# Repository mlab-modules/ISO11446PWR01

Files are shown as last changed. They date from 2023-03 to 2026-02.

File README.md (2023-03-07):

#  ISO11446PWR01 - Trailer emulator

[ISO 11446 specifies a 13-pole electrical connector](https://en.wikipedia.org/wiki/ISO_standards_for_trailer_connectors#13-pin_trailer_connector_(ISO_11446)) between towing and towed vehicles with 12 volt electrical system. The module emulates connection of the trailer to get power supply and commands signals for connected devices. 

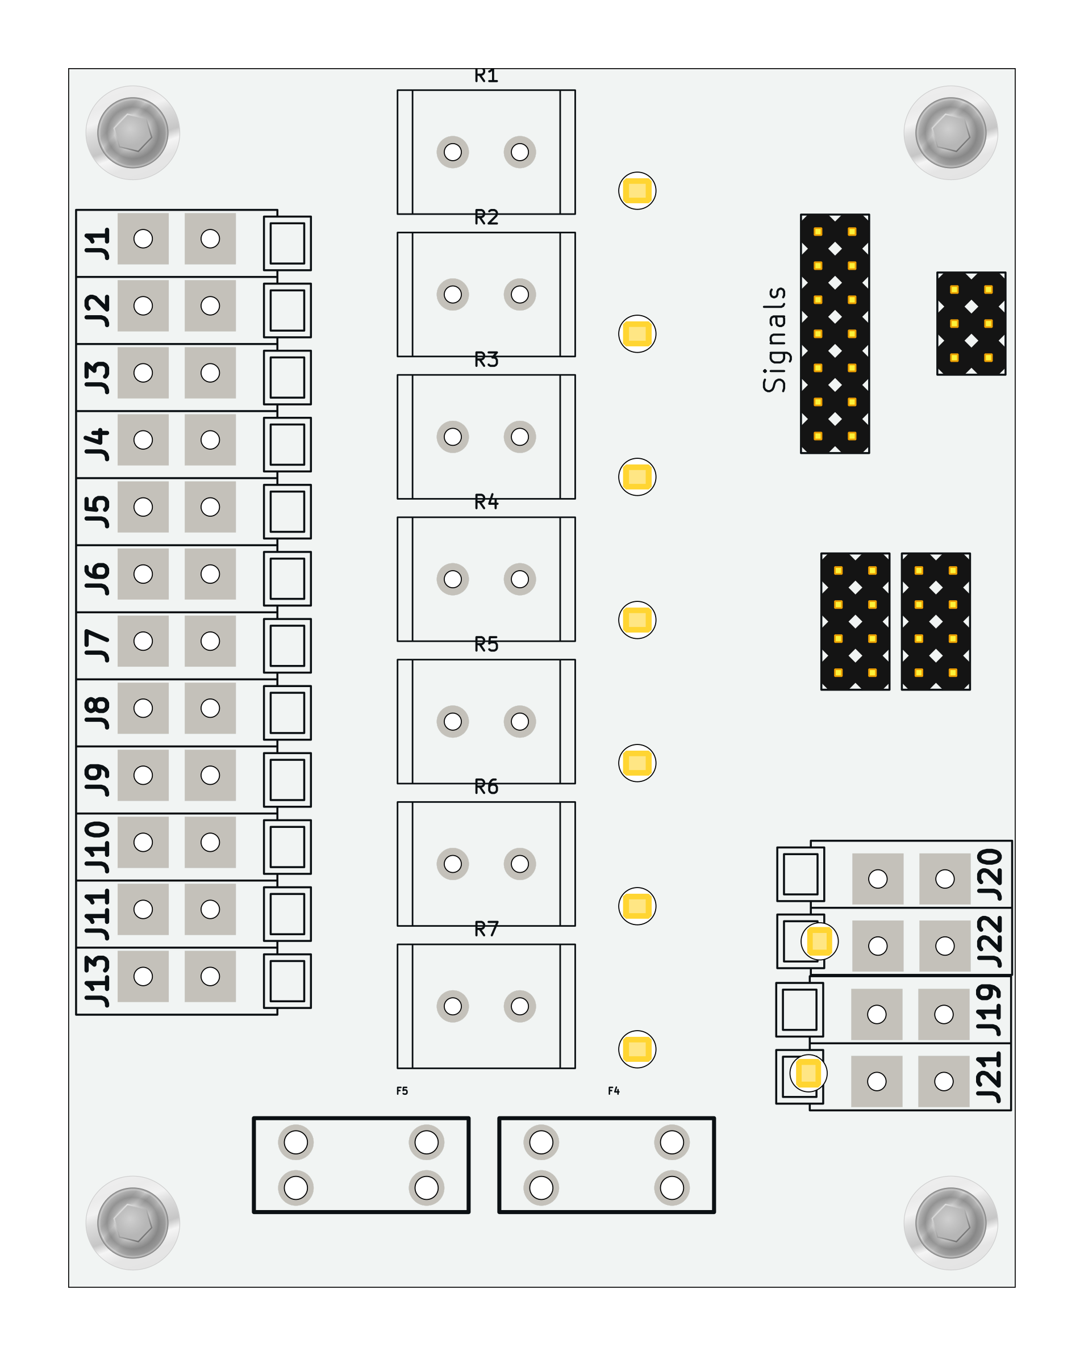
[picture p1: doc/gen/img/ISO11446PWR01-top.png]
ISO11446PWR01 PCB top


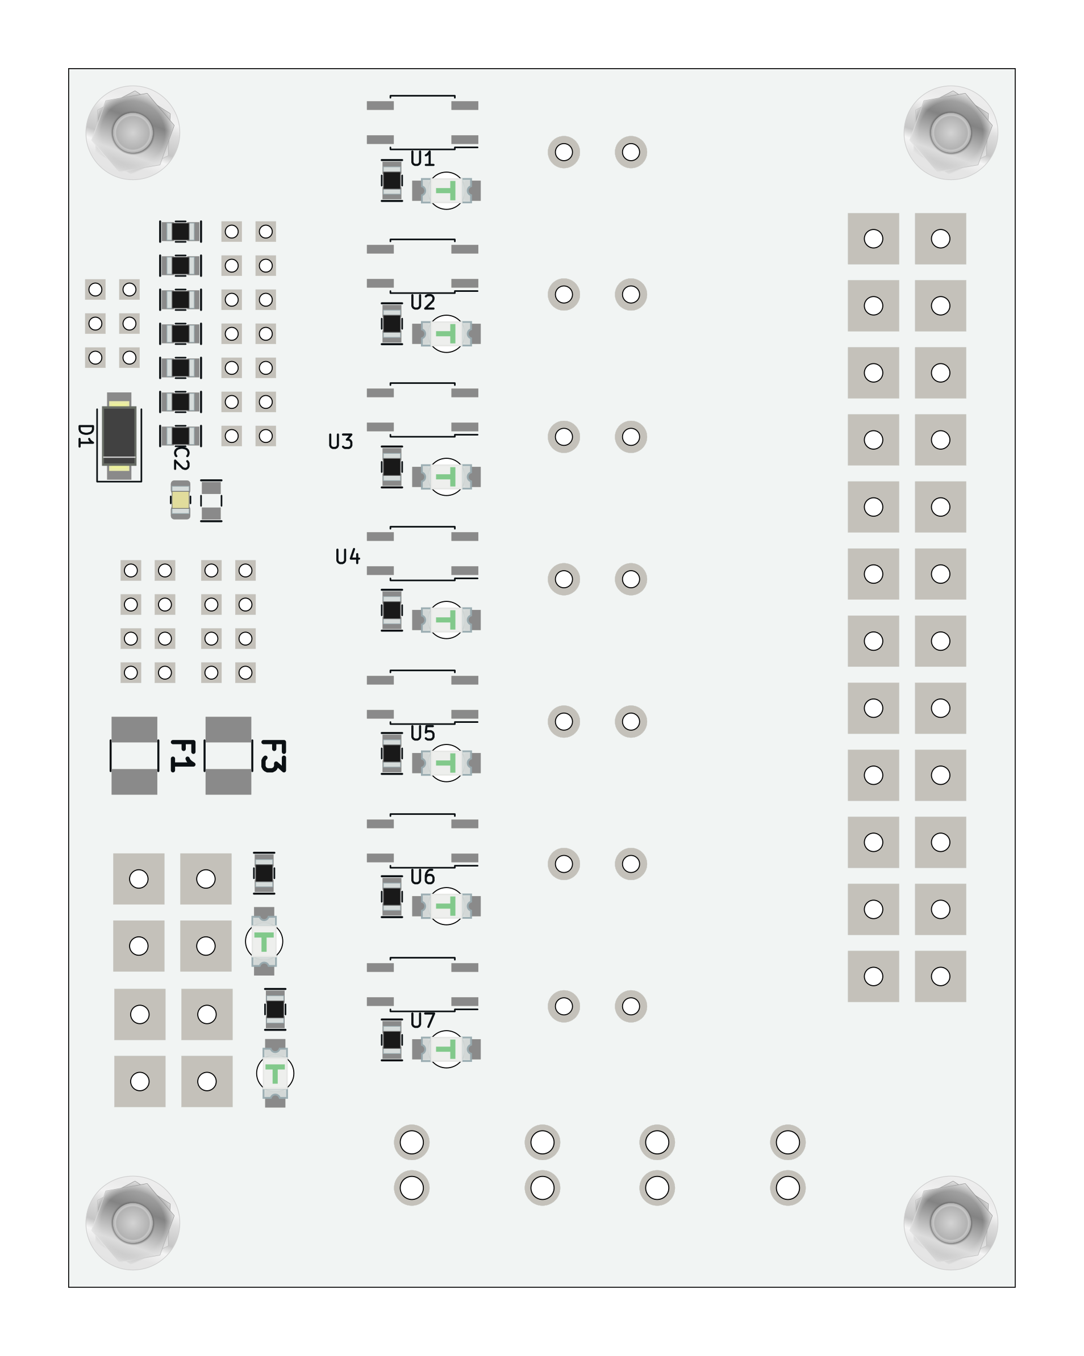
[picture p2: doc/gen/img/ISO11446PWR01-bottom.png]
ISO11446PWR01 PCB bottom


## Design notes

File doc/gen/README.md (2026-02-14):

# PCB

Board size: 70.61x90.93 mm (2.78x3.58 inches)

- This is the size of the rectangle that contains the board
- Thickness: 1.6 mm (63 mils)
- Material: FR4
- Finish: HAL
- Layers: 2
- Copper thickness: 35 µm

Solder mask: TOP / BOTTOM

- Color: Green

Silk screen: TOP / BOTTOM

- Color: White

# Important sizes

Clearance: 0.2 mm (8 mils)

Track width: N/A mm (N/A mils)

- By design rules: 0.2 mm (8 mils)

Drill: 1.0 mm (39 mils)

- Vias: N/A mm (N/A mils) [Design: 0.4 mm (16 mils)]
- Pads: 1.0 mm (39 mils)
- The above values are real drill sizes, they add 0.1 mm (4 mils) to plated holes (PTH)

Via: N/A/N/A mm (N/A/N/A mils)

- By design rules: 0.4/0.3 mm (16/12 mils)
- Micro via: yes [0.2/0.1 mm (8/4 mils)]
- Buried/blind via: yes
- Total: 0 (thru: 0 buried/blind: 0 micro: 0)

Outer Annular Ring: 0.26 mm (10 mils)

- By design rules: 0.26 mm (10 mils)

Eurocircuits class: 4A
- Using min drill 1.0 mm for an OAR of 0.26 mm

# General stats

Components count: (SMD/THT)

- Top: 0/33 (THT)
- Bottom: 37/0 (SMD)

Defined tracks:

Used tracks:

Defined vias:

Used vias:

Holes (excluding vias):

- 0.89 mm (35 mils) (36)
- 1.2 mm (47 mils) (14)
- 1.3 mm (51 mils) (32)
- 1.65 mm (65 mils) (8)
- 2.7 mm (106 mils) (9)
- 3.0 mm (118 mils) (4)

Oval holes:

Drill tools (including vias and computing adjusts and rounding):

- 1.0 mm (39 mils) (36)
- 1.3 mm (51 mils) (14)
- 1.4 mm (55 mils) (32)
- 1.75 mm (69 mils) (8)
- 2.7 mm (106 mils) (9)
- 3.1 mm (122 mils) (4)

Solder paste stats:

Using a paste with 87.75 % alloy, that has an specific gravity for the alloy of 7.4 g/cm³
and 1.0 g/cm³ for the flux. This paste has an specific gravity of  4.15 g/cm³.

The stencil thickness is  0.12 mm.

| Side | Pads with paste | Area [mm²] | Paste [g] |
|---|---|---|---|
| Total  | 88 | 147.85 | 0.74 |

Note: this is just an approximation to the theoretical value. Margins of the solder mask and waste aren't computed.

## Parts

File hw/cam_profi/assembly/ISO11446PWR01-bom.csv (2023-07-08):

Component | Description | Part | References | Value | Footprint | Quantity Per PCB | Datasheet | ust_id
1 |  | C_Small-Device-ISM02A-rescue | C2 | 100nF | C_0805_2012Metric | 1 |  | 5c70984812875079b91f8bf2
2 |  | C_Small-Device-ISM02A-rescue | C1 | 10uF | SMD-0805 | 1 |  | 5c70984812875079b91f8bbe
3 |  | D_ZENER-MLAB_D | D1 | BZV55C-5,6V | D_SMA | 1 |  | 5c70984512875079b91f88b2
4 | Light emitting diode | LED | D2D3D4D5D6D7D8D9D10 | LED | LED_1206 | 9 | ~
5 | Fuse | Fuse | F4F5 | 16A | Fuse-Keystone-3557-2 | 2 | https://www.tme.eu/cz/details/keys3557-2/automobilni-pojistkova-pouzdra/keystone/3557-2/
6 | Resettable fuse, polymeric positive temperature coefficient | Polyfuse | F1F3 | SD110-16 | 1812 | 2 | ~
7 | 2x04 2.54 mm pitch header, 2 pins next to each other are connected | HEADER_2x04_PARALLEL | J16J18 | 2x4 | Straight_2x04 | 2
8 | 2x03 2.54 mm pitch header, 2 pins next to each other are connected | HEADER_2x03_PARALLEL | J14 | 3.3-5V | Straight_2x03 | 1
9 | 2x07 2.54 mm pitch header, 2 pins next to each other are connected | HEADER_2x07_PARALLEL | J15 | Signals | Straight_2x07 | 1
10 | Generic connector, single row, 01x01, script generated (kicad-library-utils/schlib/autogen/connector/) | Conn_01x01_Female | J1J2J3J4J5J6J7J8J9J10J11J13J19J20J21J22 | WAGO 256-401 | WAGO256 | 16 | ~
11 | Resistor | R | R1R2R3R4R5R6R7 | 33R | R_Radial_Power_L13.0mm_W9.0mm_P5.00mm | 7 | ~
12 | Resistor | R | R10R11R14R15R19R20R21 | 510R | SMD-0805 | 7 | ~
13 | Resistor | R | R8R9R12R13R16R17R18R22R23 | 1k | SMD-0805 | 9 | ~
14 | DC Optocoupler, Vce 35V, CTR 50%, SO-4 | LTV-357T | U1U2U3U4U5U6U7 | LTV-357T | SO-4_4.4x3.6mm_P2.54mm | 7 | https://www.buerklin.com/medias/sys_master/download/download/h91/ha0/8892020588574.pdf | 5c70984412875079b91f8789

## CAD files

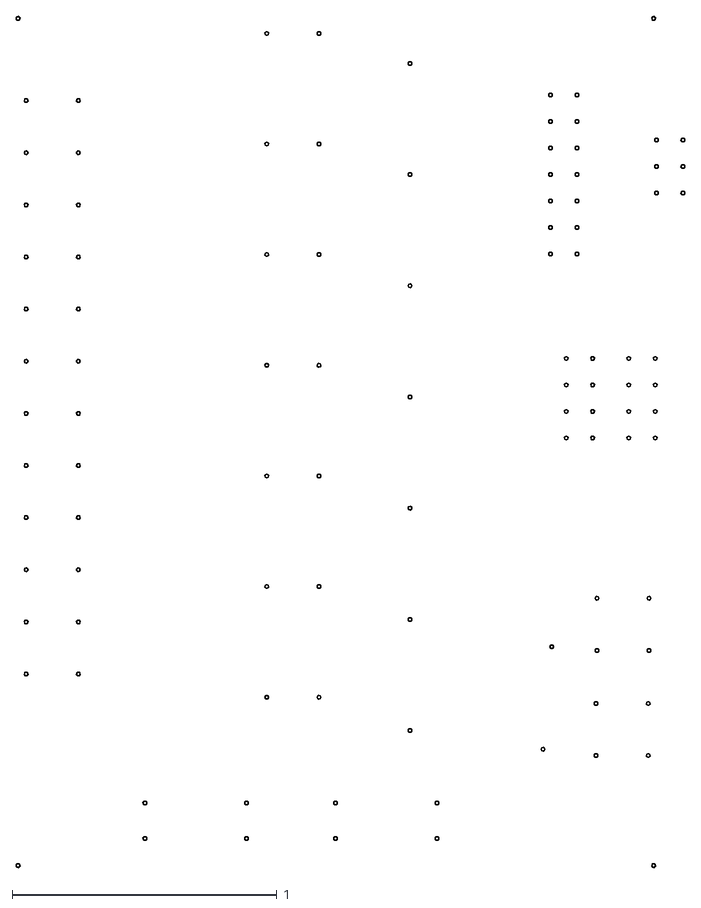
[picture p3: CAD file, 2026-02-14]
doc/gen/dxf/ISO11446PWR01-User_Eco2.dxf
2.52 x 3.21

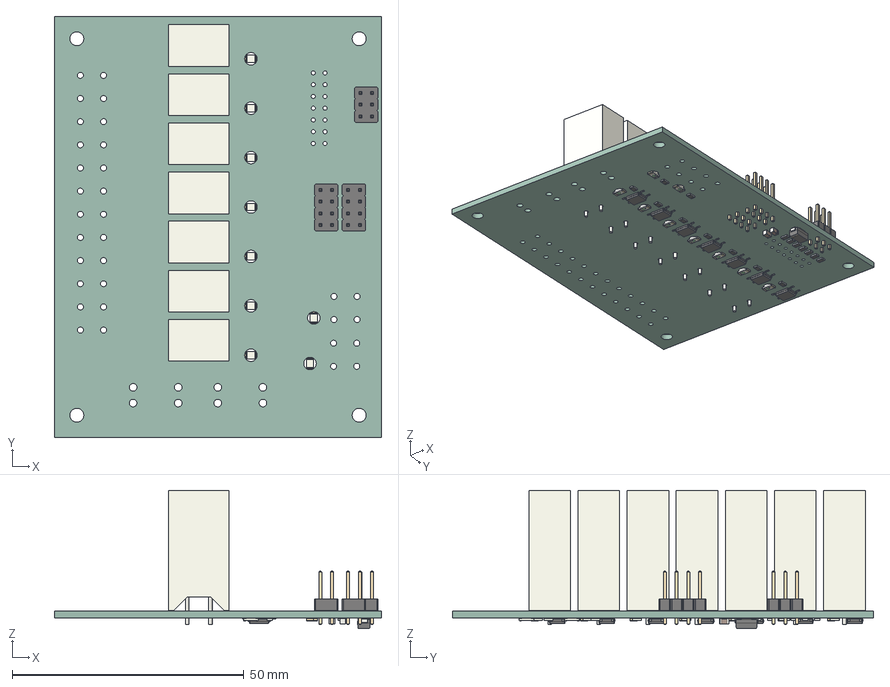
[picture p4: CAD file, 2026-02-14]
doc/gen/ISO11446PWR01.step
70.6 x 90.9 x 29.9 mm
R_Radial_Power_L13.0mm_W9.0mm_P5.00mm x 7
PinHeader_2x04_P2.54mm_Vertical x 2
PinHeader_2x03_P2.54mm_Vertical
LED_1206_3216Metric x 9
R_0805_2012Metric x 16
SO-4_4.4x3.6mm_P2.54mm x 7
C_0805_2012Metric x 2
D_SMA
kibot_23s9yeyt_PCB

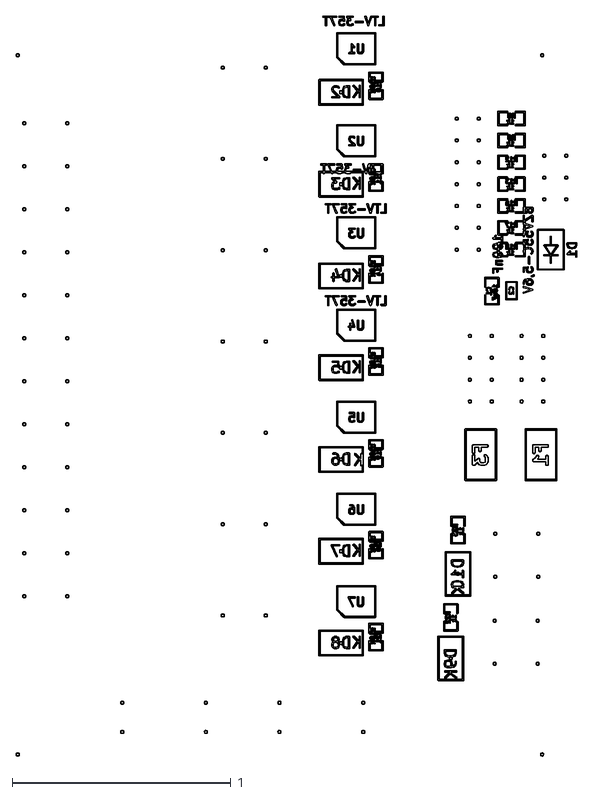
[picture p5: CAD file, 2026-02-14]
doc/gen/dxf/ISO11446PWR01-B_Fab.dxf
2.57 x 3.39

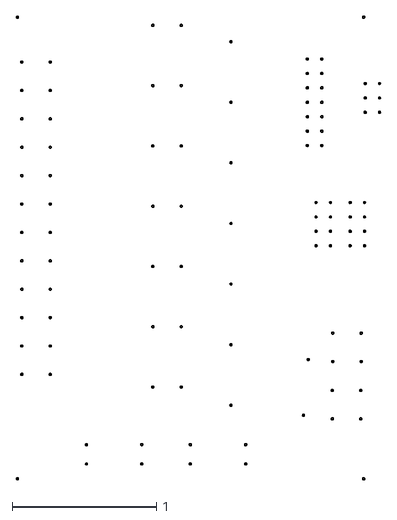
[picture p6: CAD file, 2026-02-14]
doc/gen/dxf/ISO11446PWR01-B_Adhesive.dxf
2.52 x 3.21

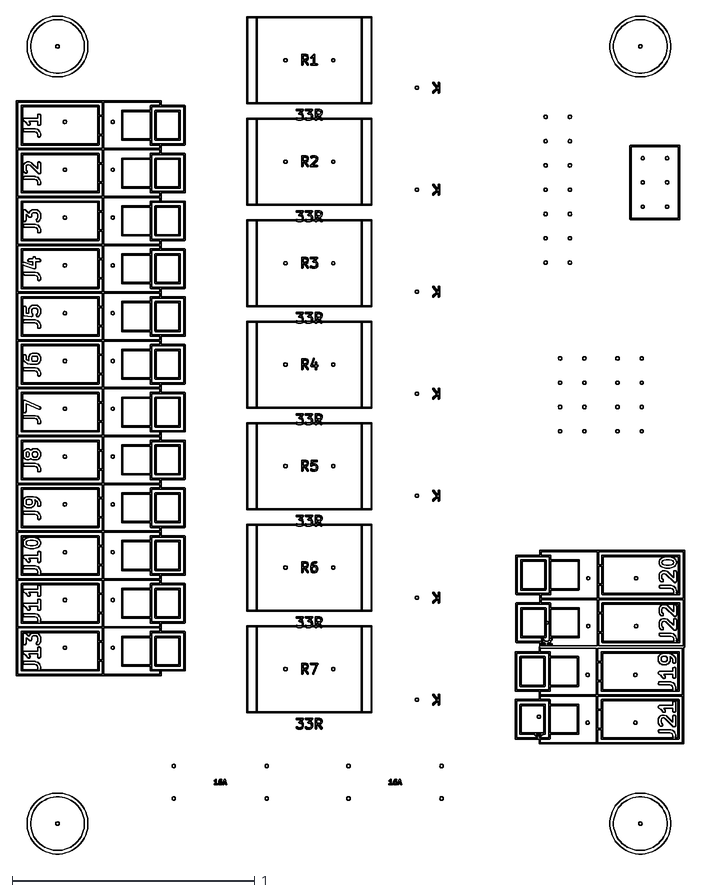
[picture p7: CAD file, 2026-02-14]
doc/gen/dxf/ISO11446PWR01-F_Fab.dxf
2.75 x 3.45

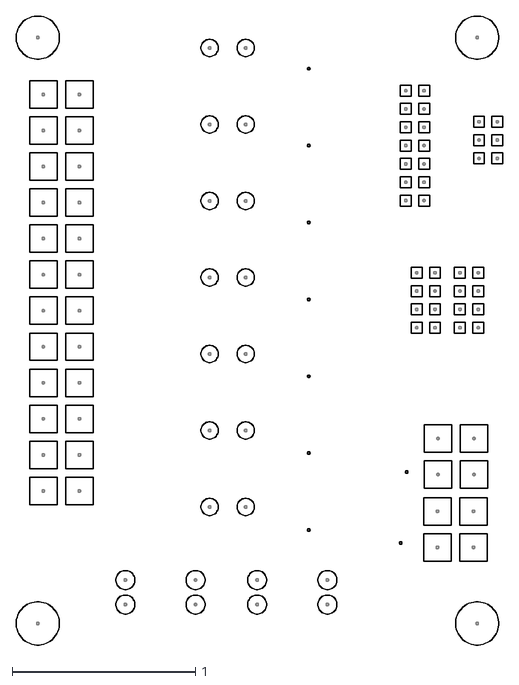
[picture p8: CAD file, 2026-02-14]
doc/gen/dxf/ISO11446PWR01-F_Cu.dxf
2.66 x 3.44

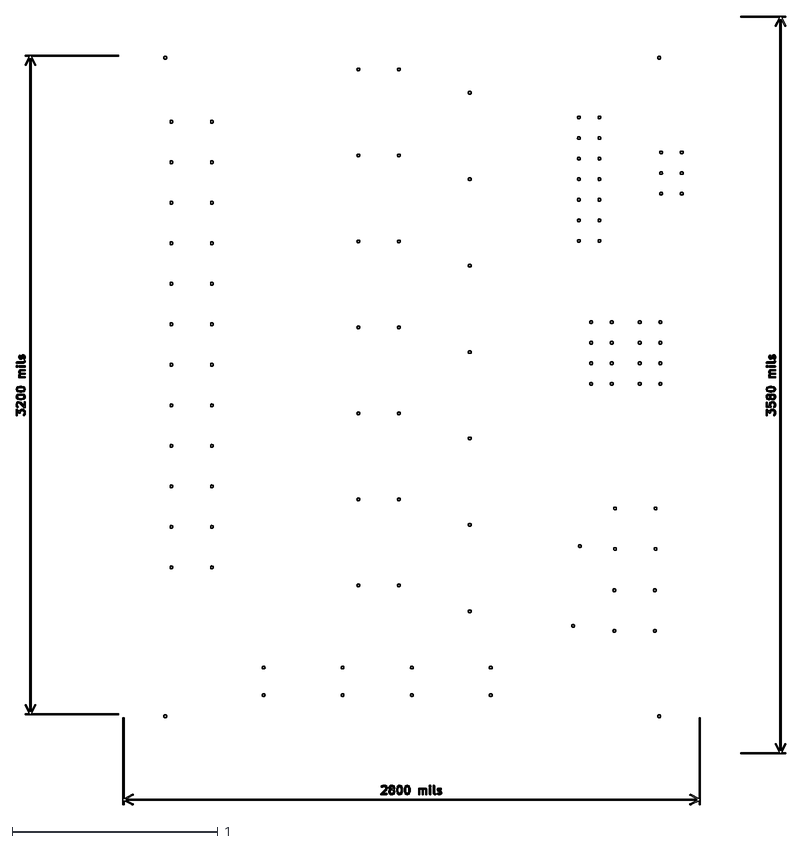
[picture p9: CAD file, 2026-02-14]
doc/gen/dxf/ISO11446PWR01-User_Comments.dxf
3.74 x 3.83

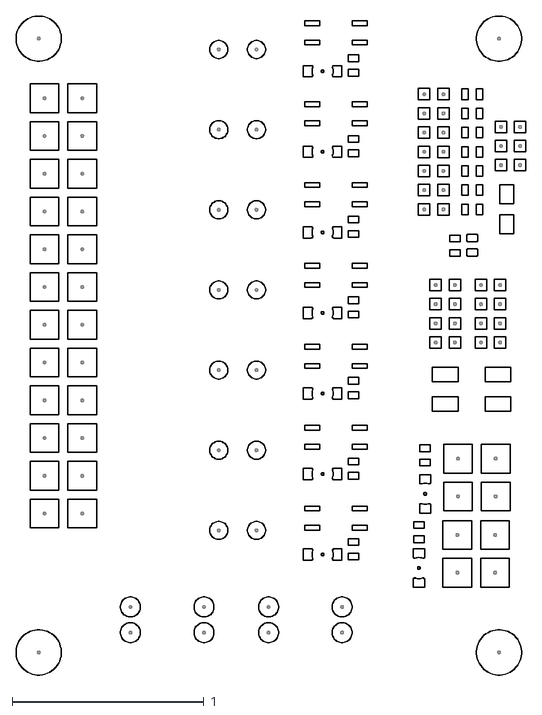
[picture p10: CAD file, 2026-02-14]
doc/gen/dxf/ISO11446PWR01-B_Cu.dxf
2.66 x 3.44

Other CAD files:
doc/gen/dxf/ISO11446PWR01-B_Courtyard.dxf
doc/gen/dxf/ISO11446PWR01-B_Mask.dxf
doc/gen/dxf/ISO11446PWR01-B_Paste.dxf
doc/gen/dxf/ISO11446PWR01-B_Silkscreen.dxf
doc/gen/dxf/ISO11446PWR01-Edge_Cuts.dxf
doc/gen/dxf/ISO11446PWR01-F_Courtyard.dxf
doc/gen/dxf/ISO11446PWR01-F_Mask.dxf
doc/gen/dxf/ISO11446PWR01-F_Silkscreen.dxf

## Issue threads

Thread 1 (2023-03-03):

Power supply availability test

kaklik, 2023-03-03:
Zkusil jsem udělat jednoduchý test pomocí zapojení, které jsem vytvořil z výkonových rezistorů podle  [wiki stránky s popisem ISO_11446](https://cs.wikipedia.org/wiki/ISO_11446). Pro vyzkoušení jsem použil náhodné výkonové rezistory mezi 33-56 Ohm.

Výsledkem je, že Karoq korektně detekoval přívěs

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

Zároveň začaly být měřitelná obě výstupní napájení. Tohle je spínané napájení, které je k dispozici jen při nastartovaném motoru (nestačí zapnuté zapalování).

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

Tohle je trvalé napájení, které je přítomné i když je auto zamčené.

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

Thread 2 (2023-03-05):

Connecting cable

kaklik, 2023-03-05:
Aby emulátor dával smysl, tak se musí připojit k zásuvce přívěsu z kufru auta. To ale znamená použít 12ti žilový kabel, který se skřípne do kufru, tak aby po něm netekla dovnitř voda.

Znamená to do kufru přivést poměrně [tlustý kabel](https://www.tme.eu/cz/details/heat180sihf-12g1.5/vicezilove-kabely-silikonove/lapp/0046039/), protože průřez napájecích vodičů v autozásuvce je 2.5mm², tak je nemá smysl připojovat menším průřezem než 1.5mm².

Existují i [ploché kabely](https://www.tme.eu/cz/details/neo-flach-12g1.5/vicezilove-kabely-nestinene/helukabel/28006/), ale jsou dost drahé.

roman-dvorak, 2023-03-05:
Jsou dvě možná řešení:

1) Vícežilový kabel s menším průřezem, kde výkonové vodiče budou znásobeny.

2) Rozdělit to na více kabelů. Pro to by bylo podstatné zjistit, jestli koule může být v zavřeném stavu. Pak by tím bylo vyřešeno krytí proti vodě.

kaklik, 2023-03-05:
> Jsou dvě možná řešení:
>
>     1. Vícežilový kabel s menším průřezem, kde výkonové vodiče budou znásobeny.

Tohle řešení nevychází tak, že by to snižovalo celkový průměr kabelu.

>
>     2. Rozdělit to na více kabelů. Pro to by bylo podstatné zjistit, jestli koule může být v zavřeném stavu. Pak by tím bylo vyřešeno krytí proti vodě.

To krytí proti vodě se tím nevyřeší. Na ten konektor ze spodu normálně bude cákat voda. Předpokládám, že může být v zavřeném stavu, ale nevidim moc co by se tím získalo. Vzhledem k tomu, že při aktivaci vozíku přestanou fungovat ultrazvukové parkovací senzory, tak to není zrovna moc pro trvalý zapojení.

>
> (plochý kabel bude mít s vodotěsností v konetoru stejný problém jako větší počet tenčích kabelů)

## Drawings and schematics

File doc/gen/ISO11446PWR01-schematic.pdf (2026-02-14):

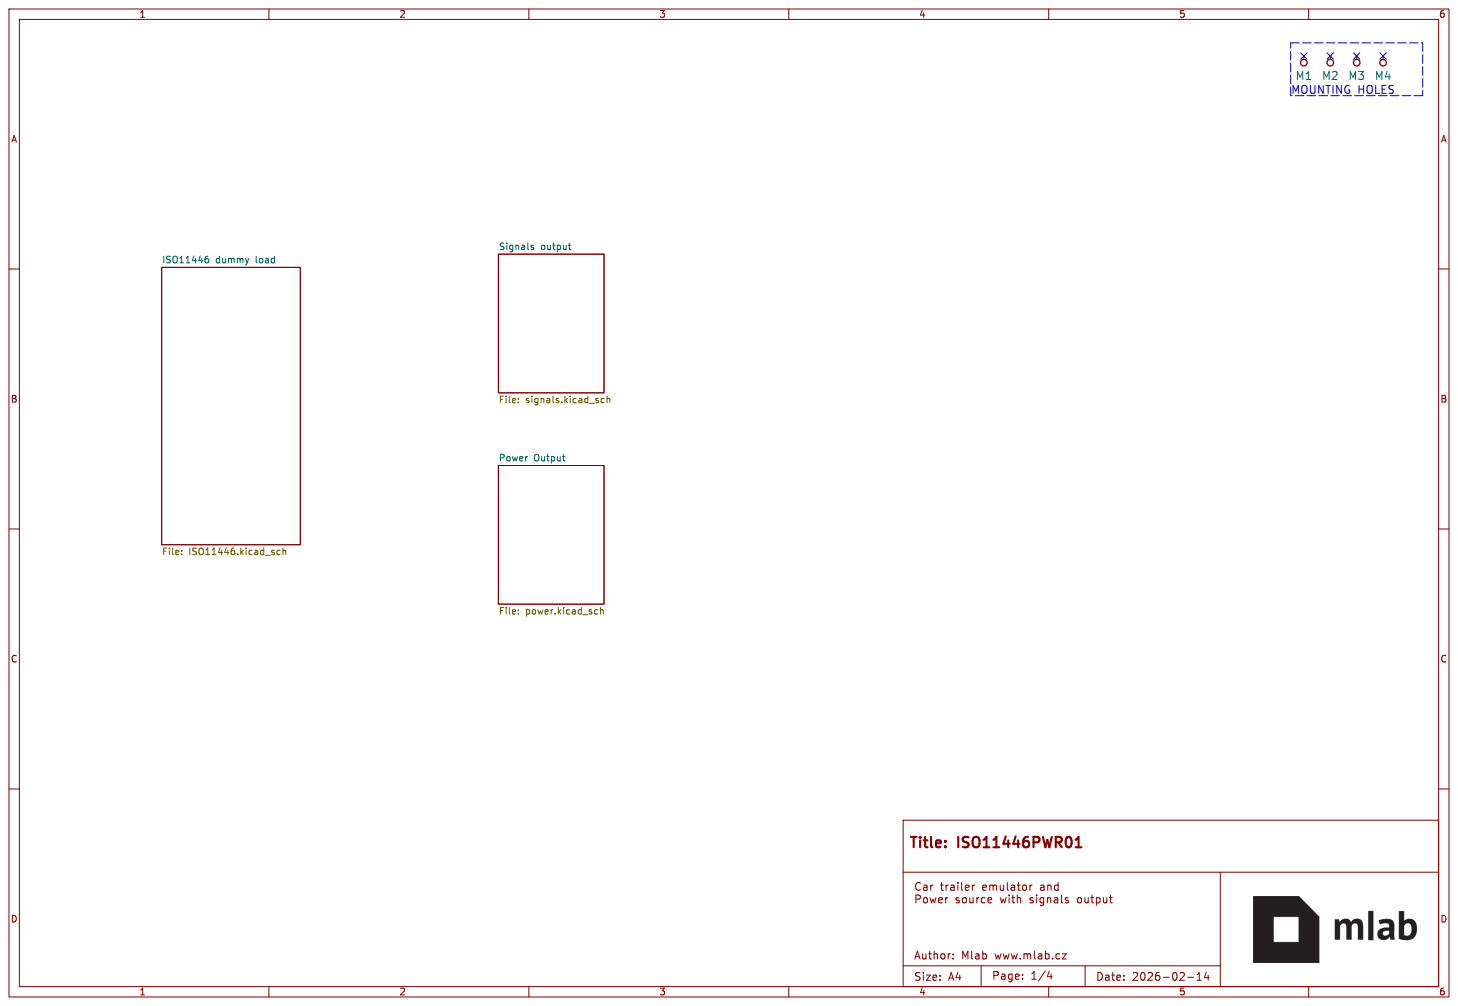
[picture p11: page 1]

Signals output File: signals.kicad_sch

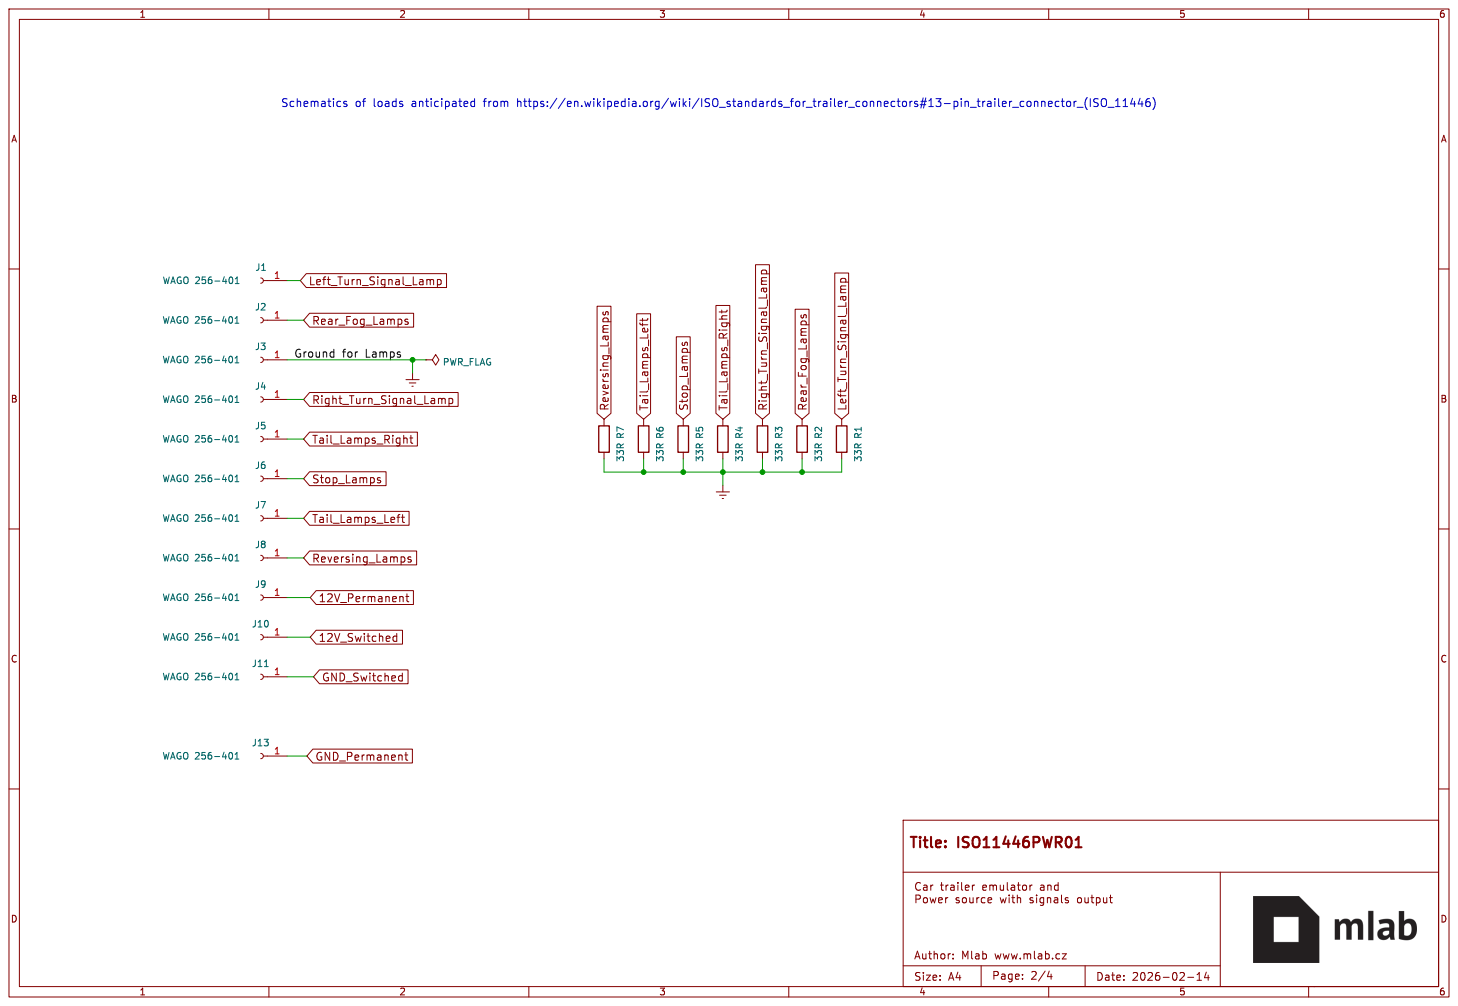
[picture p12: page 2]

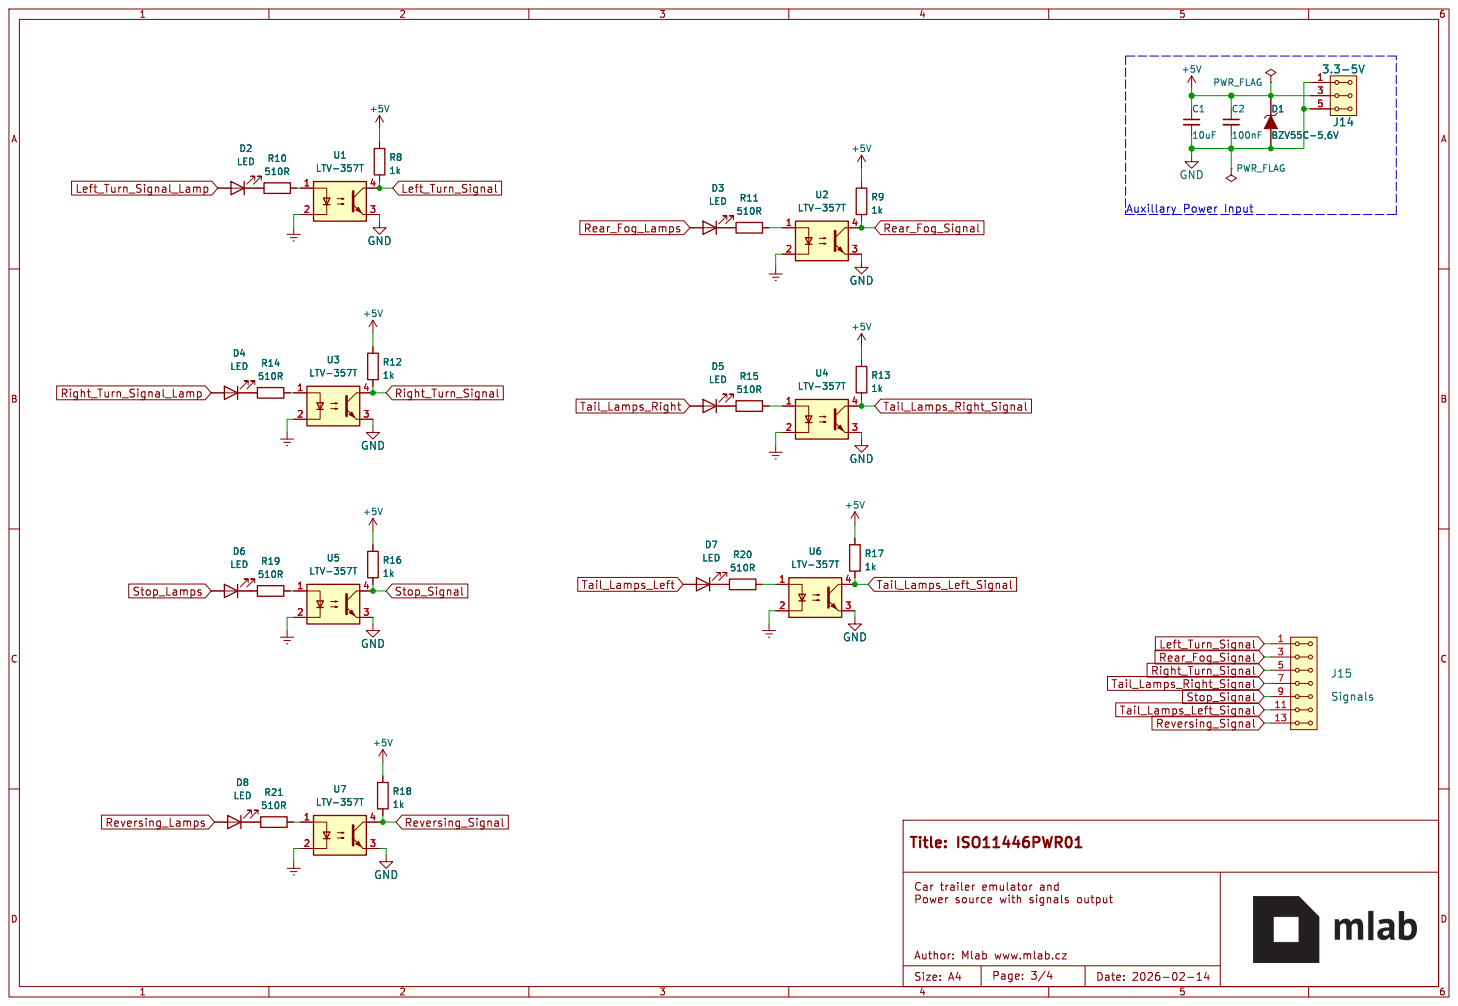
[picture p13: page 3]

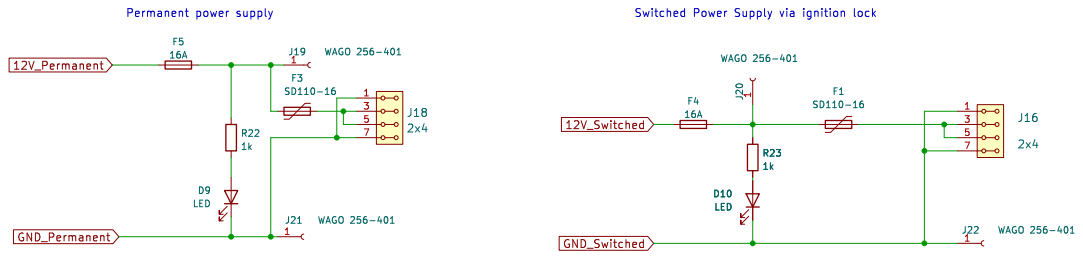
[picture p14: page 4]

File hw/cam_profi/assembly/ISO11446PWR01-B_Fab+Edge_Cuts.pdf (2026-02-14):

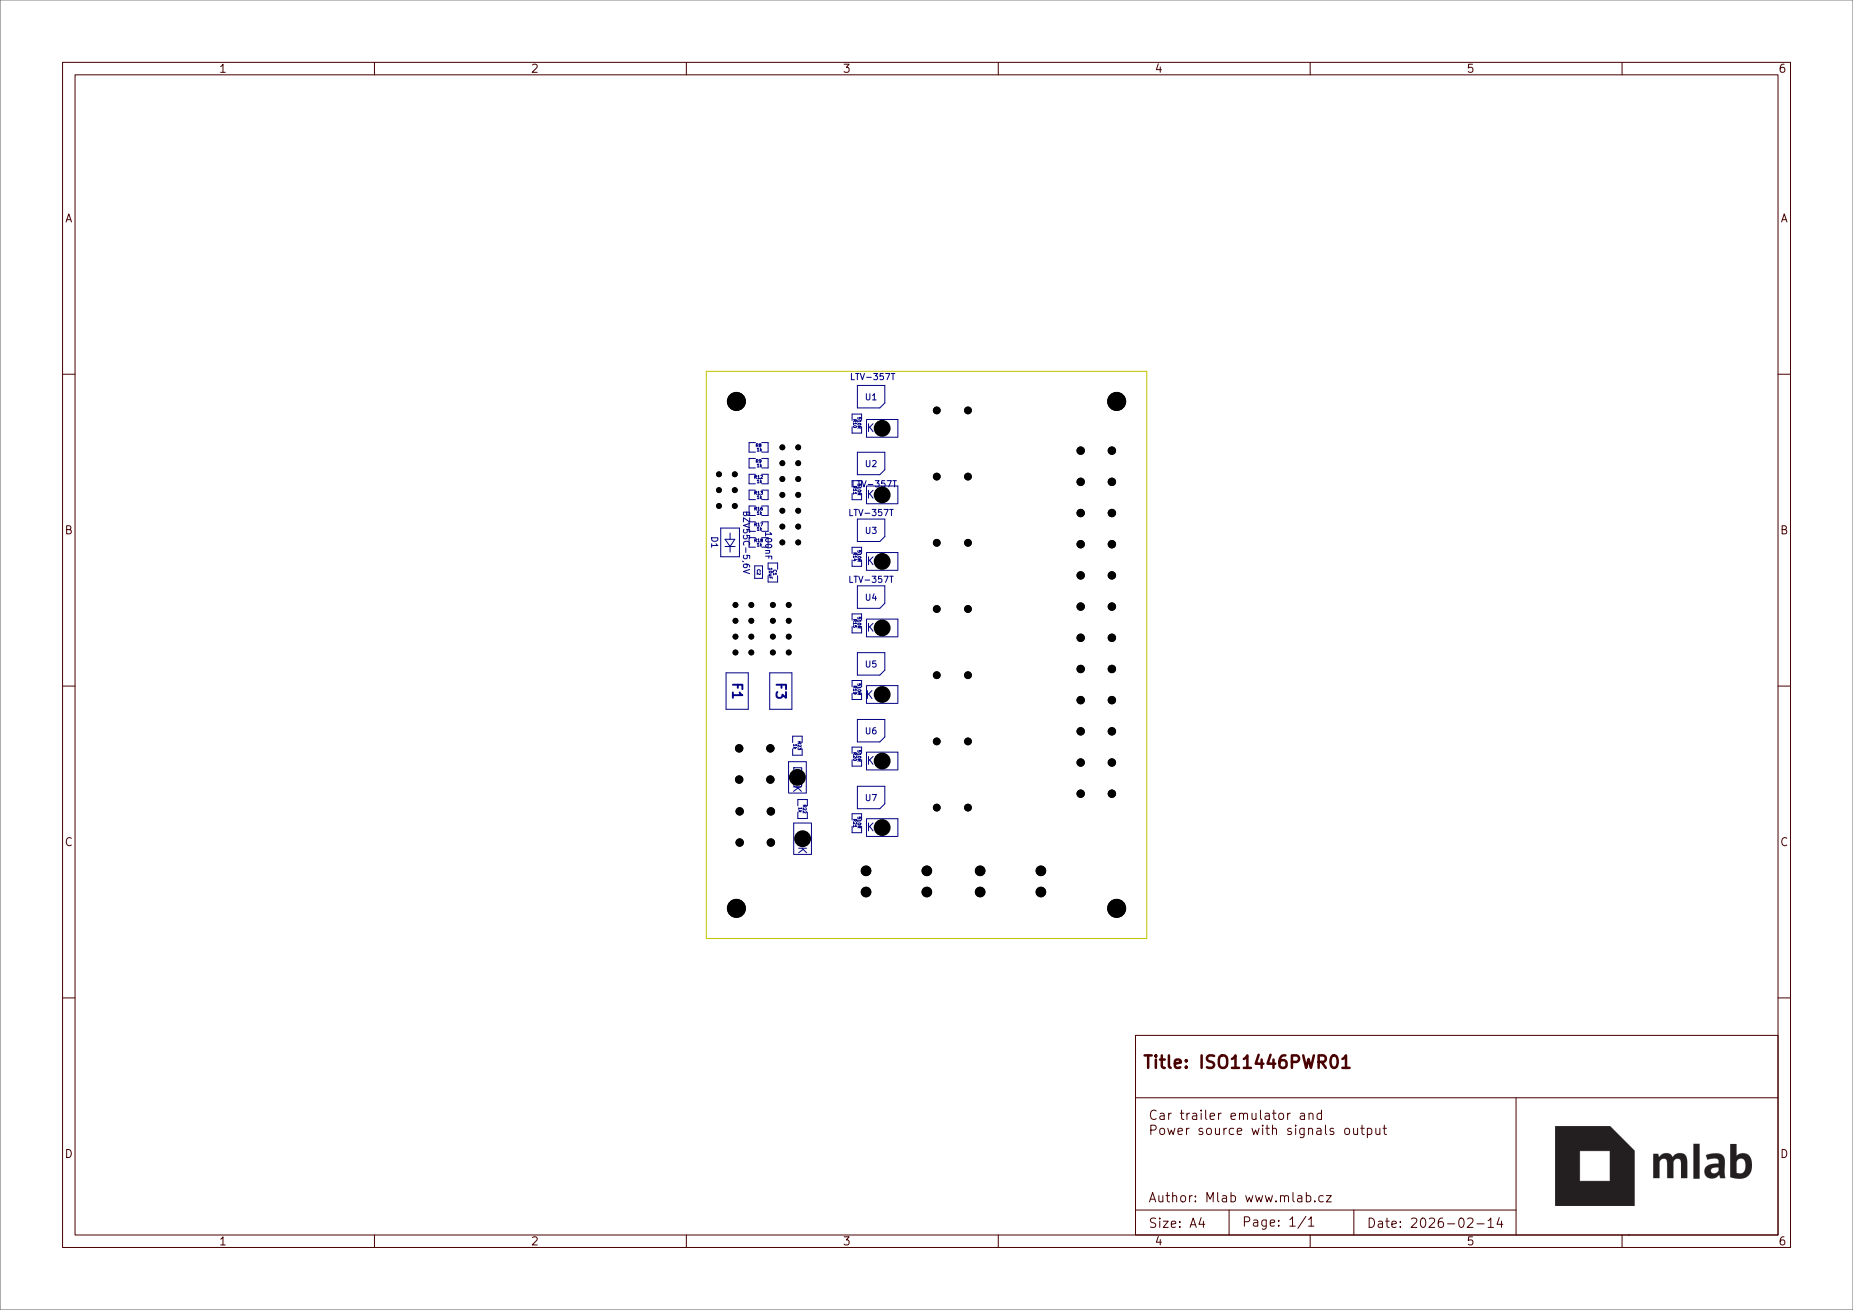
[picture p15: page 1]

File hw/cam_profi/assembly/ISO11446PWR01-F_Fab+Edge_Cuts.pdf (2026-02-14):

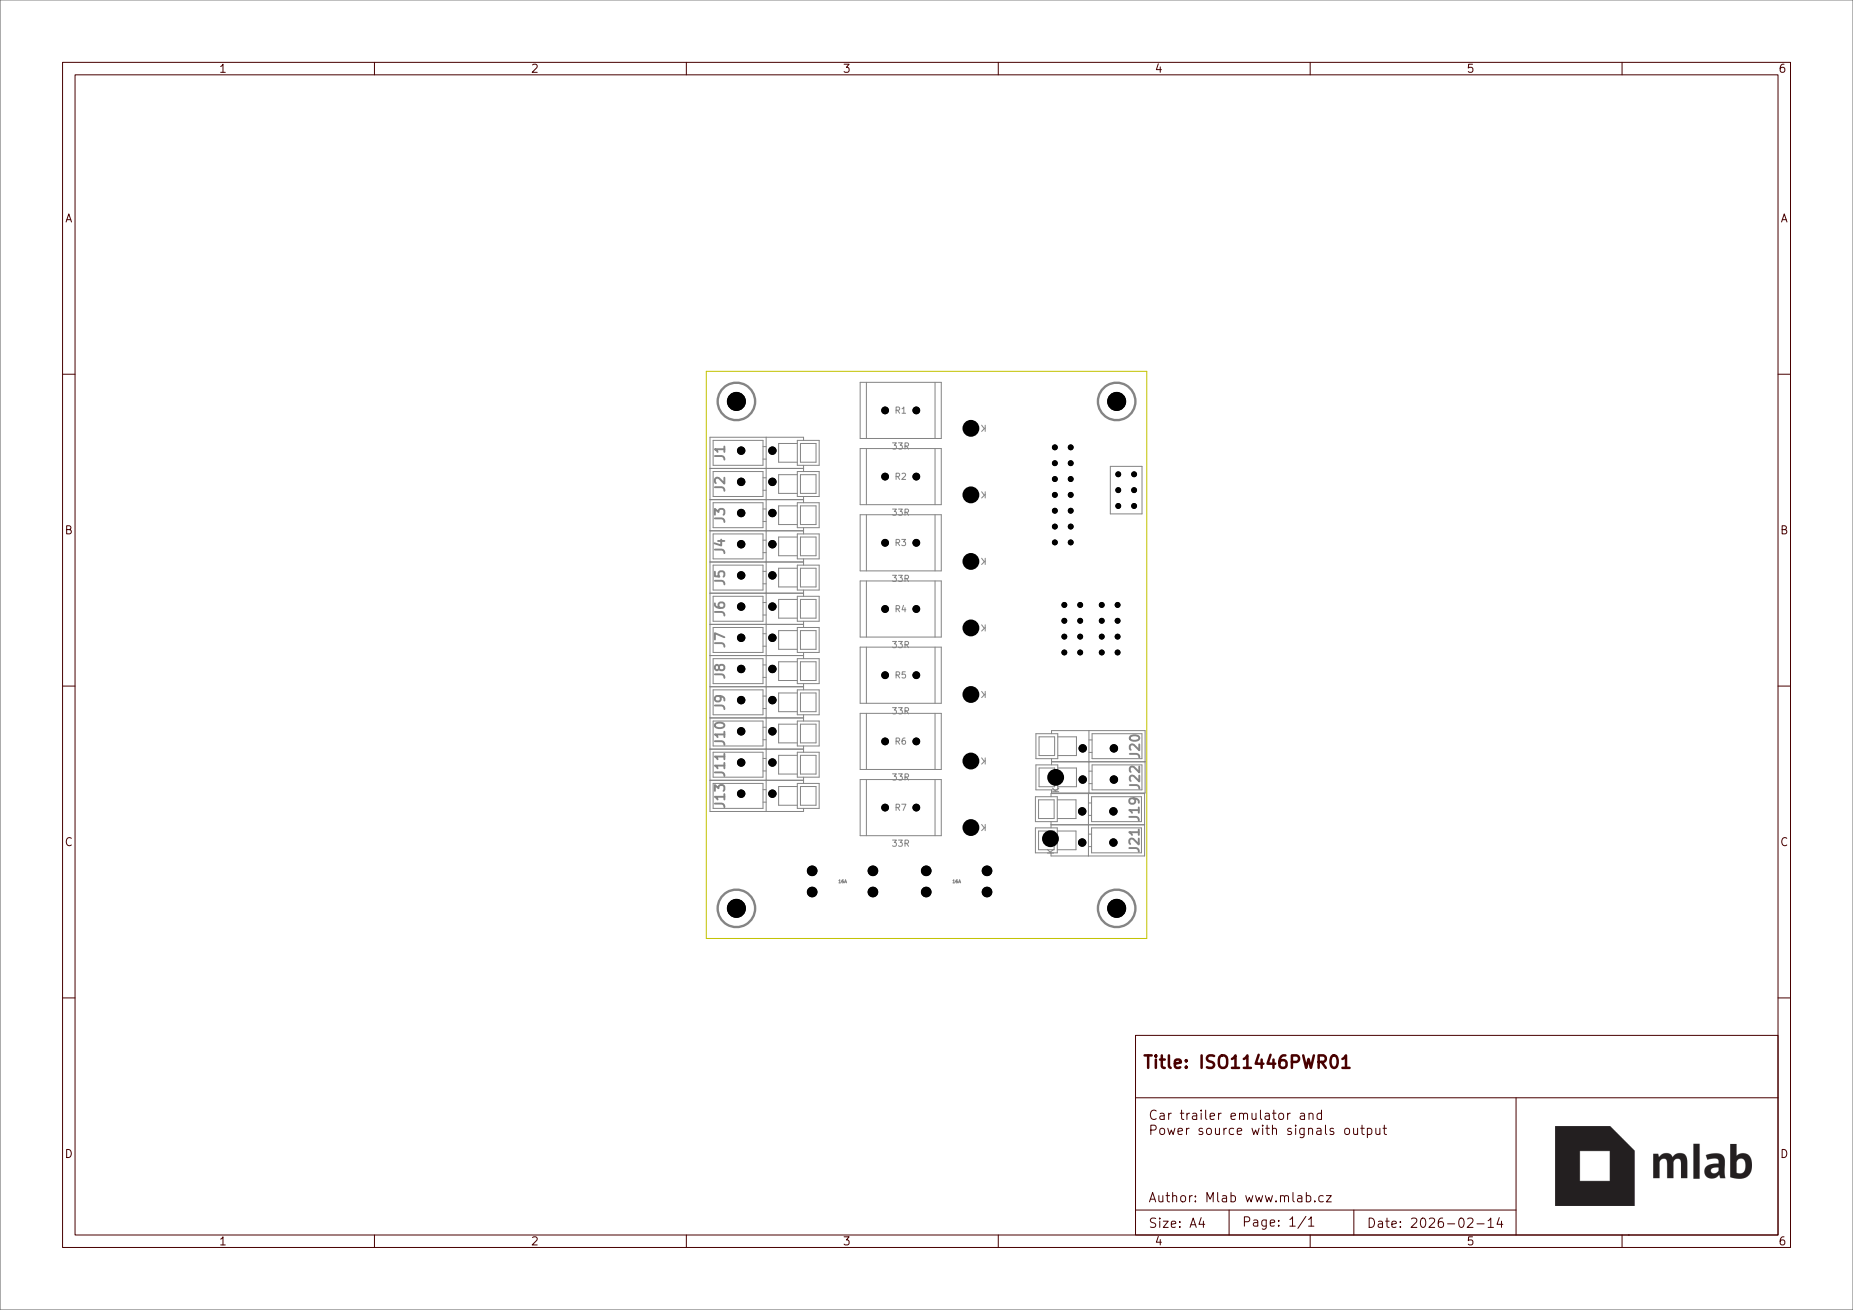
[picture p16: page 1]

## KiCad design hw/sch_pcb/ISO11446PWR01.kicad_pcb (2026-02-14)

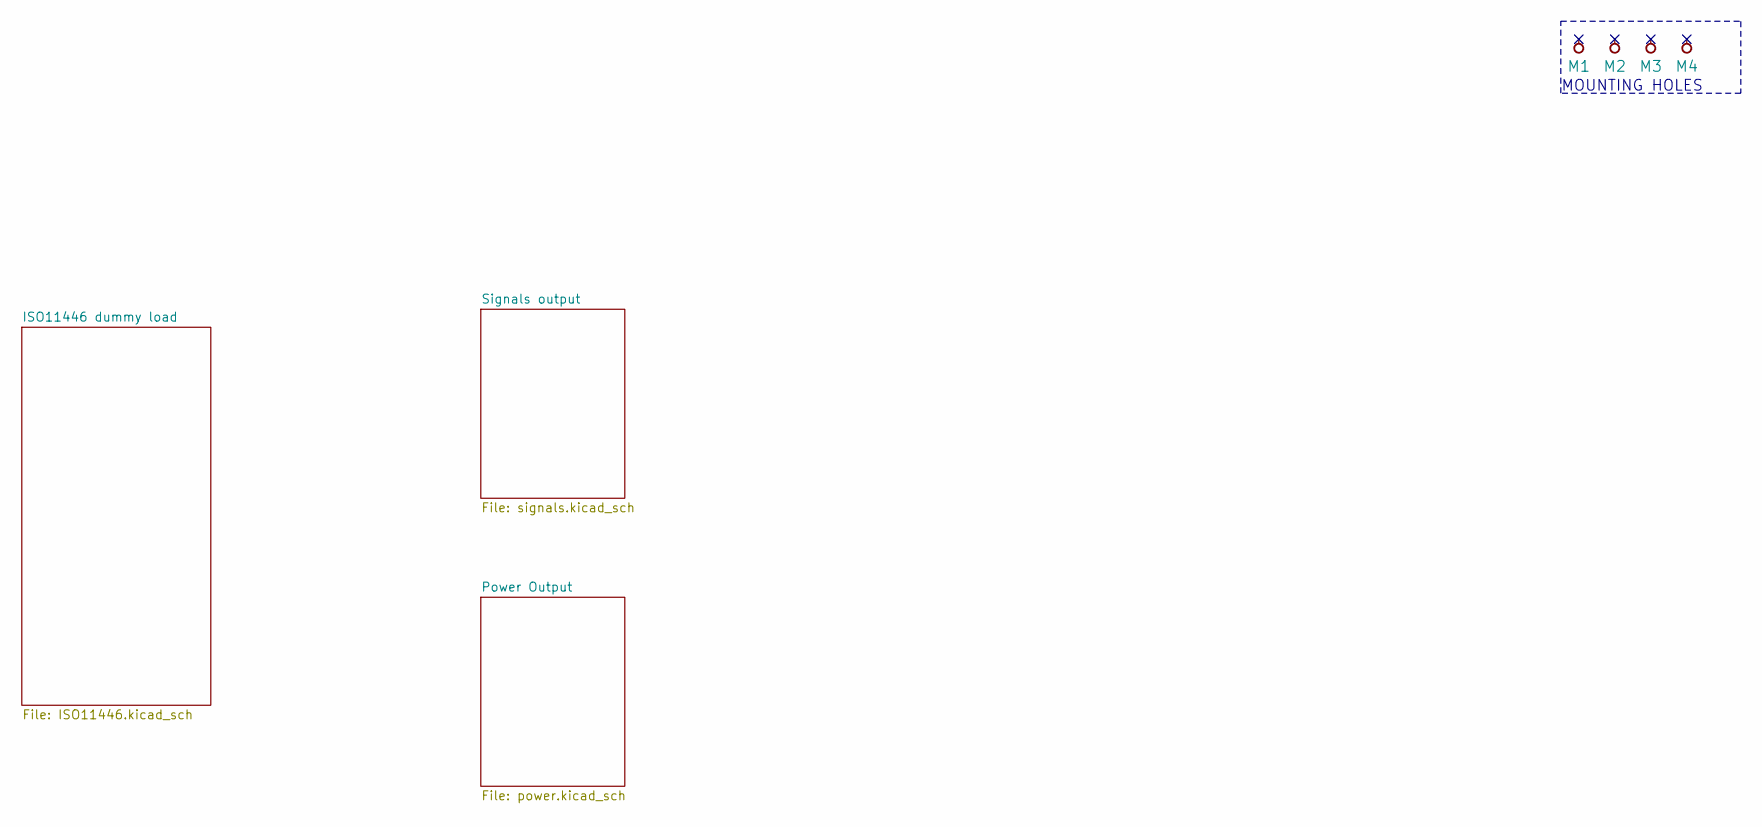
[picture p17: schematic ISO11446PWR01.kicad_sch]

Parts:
M1, M2: HOLE M3; MountingHole_3mm
M3, M4: HOLE; MountingHole_3mm

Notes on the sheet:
MOUNTING HOLES

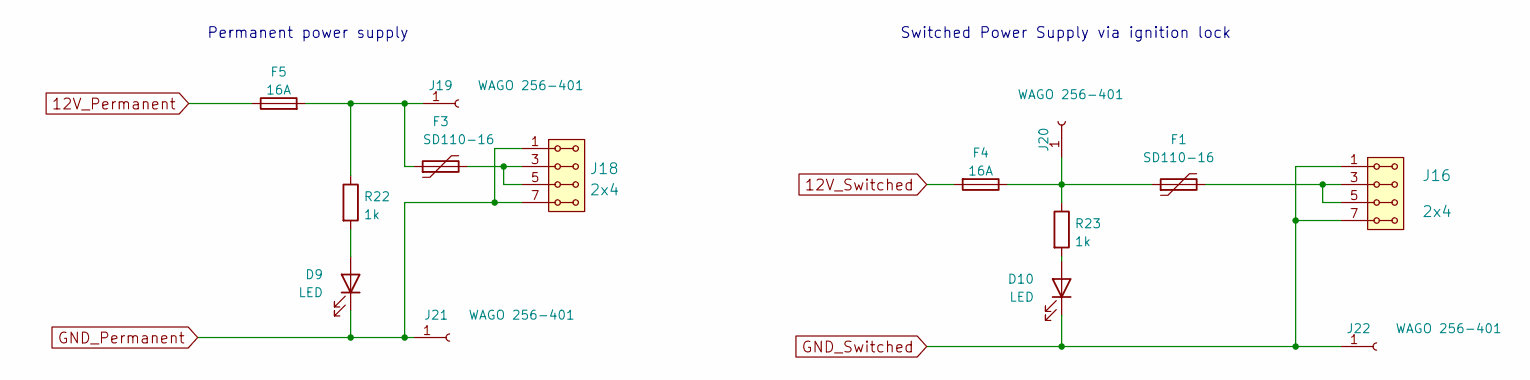
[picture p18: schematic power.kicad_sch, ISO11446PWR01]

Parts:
D9, D10: LED; LED_1206
F1, F3: SD110-16; 1812
F4, F5: 16A; Fuse-Keystone-3557-2
J16, J18: 2x4; Straight_2x04
J19, J20, J21, J22: WAGO 256-401; WAGO256
R22, R23: 1k; SMD-0805

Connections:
12V_Permanent: F5.1; also elsewhere on the board
12V_Switched: F4.2; also elsewhere on the board
GND_Permanent: D9.1 (K), J18.1, J18.2, J18.7, J18.8, J21.1; also elsewhere on the board
GND_Switched: D10.1 (K), J16.1, J16.2, J16.7, J16.8, J22.1; also elsewhere on the board
unnamed: D9.2 (A), R22.2
unnamed: D10.2 (A), R23.2
unnamed: F1.1, F4.1, J20.1, R23.1
unnamed: F1.2, J16.3, J16.4, J16.5, J16.6
unnamed: F3.1, F5.2, J19.1, R22.1
unnamed: F3.2, J18.3, J18.4, J18.5, J18.6

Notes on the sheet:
Permanent power supply
Switched Power Supply via ignition lock

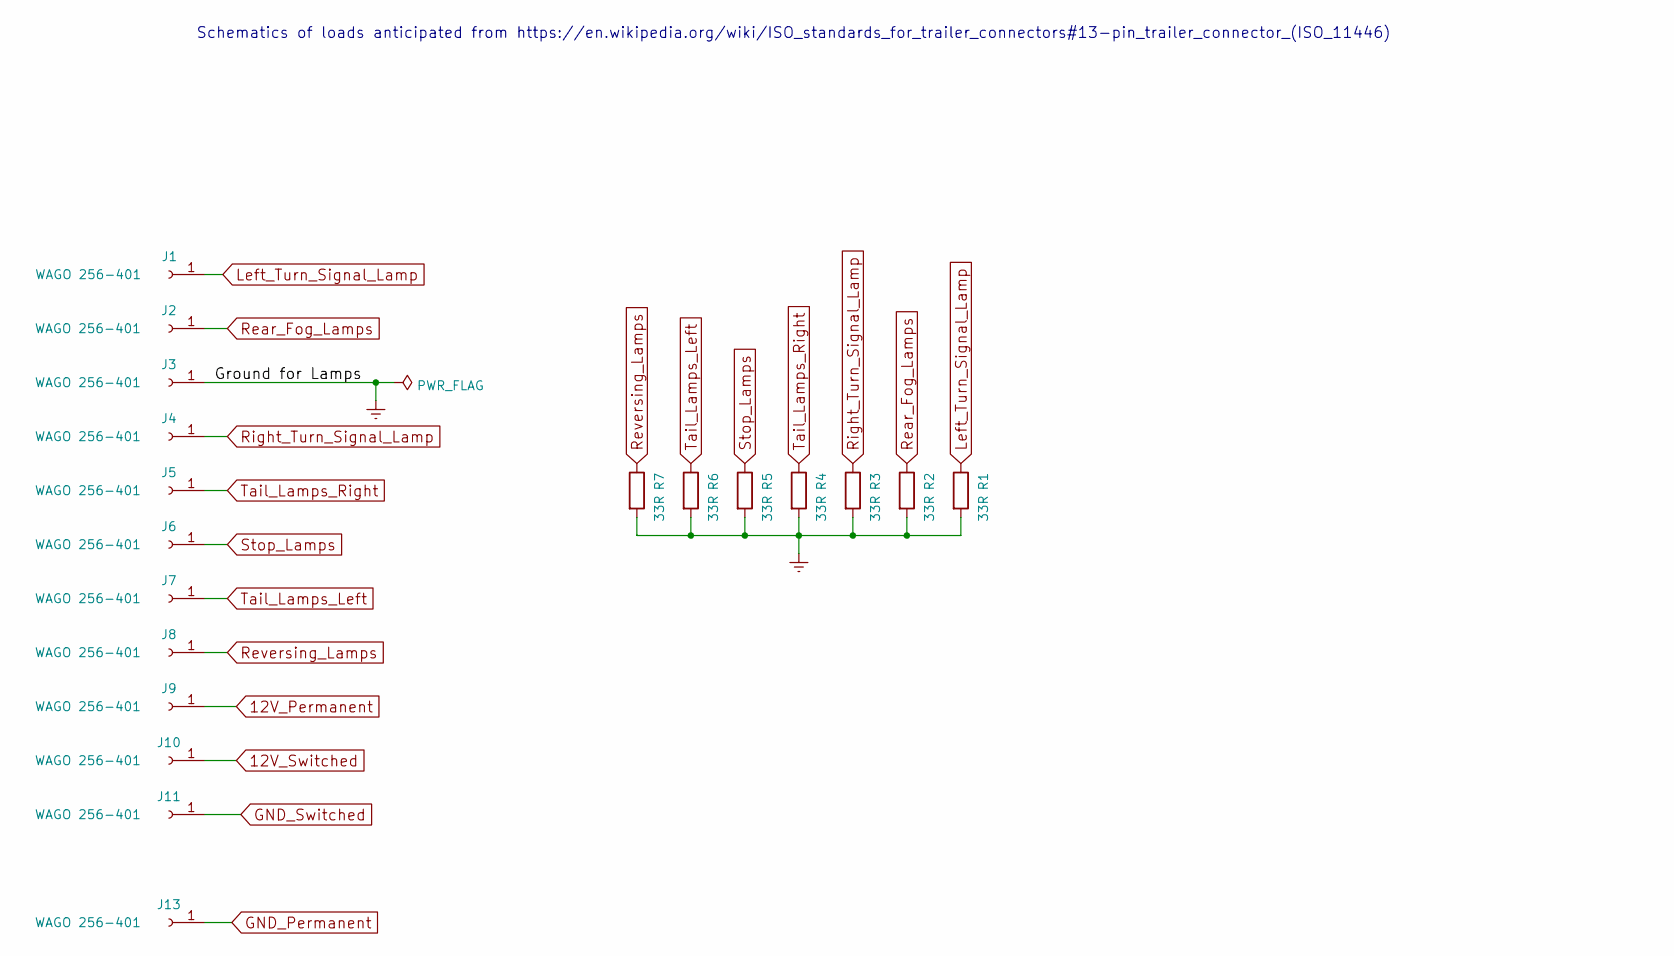
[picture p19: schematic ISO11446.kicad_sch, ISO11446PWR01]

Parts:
J1, J2, J3, J4, J5, J6, J7, J8, J9, J10, J11, J13: WAGO 256-401; WAGO256
R1, R2, R3, R4, R5, R6, R7: 33R; R_Radial_Power_L13.0mm_W9.0mm_P5.00mm

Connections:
12V_Permanent: J9.1; also elsewhere on the board
12V_Switched: J10.1; also elsewhere on the board
Earth: J3.1, R1.2, R2.2, R3.2, R4.2, R5.2, R6.2, R7.2; also elsewhere on the board
GND_Permanent: J13.1; also elsewhere on the board
GND_Switched: J11.1; also elsewhere on the board
Left_Turn_Signal_Lamp: J1.1, R1.1; also elsewhere on the board
Rear_Fog_Lamps: J2.1, R2.1; also elsewhere on the board
Reversing_Lamps: J8.1, R7.1; also elsewhere on the board
Right_Turn_Signal_Lamp: J4.1, R3.1; also elsewhere on the board
Stop_Lamps: J6.1, R5.1; also elsewhere on the board
Tail_Lamps_Left: J7.1, R6.1; also elsewhere on the board
Tail_Lamps_Right: J5.1, R4.1; also elsewhere on the board

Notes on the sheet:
Schematics of loads anticipated from https://en.wikipedia.org/wiki/ISO_standards_for_trailer_connectors#13-pin_trailer_connector_(ISO_11446)

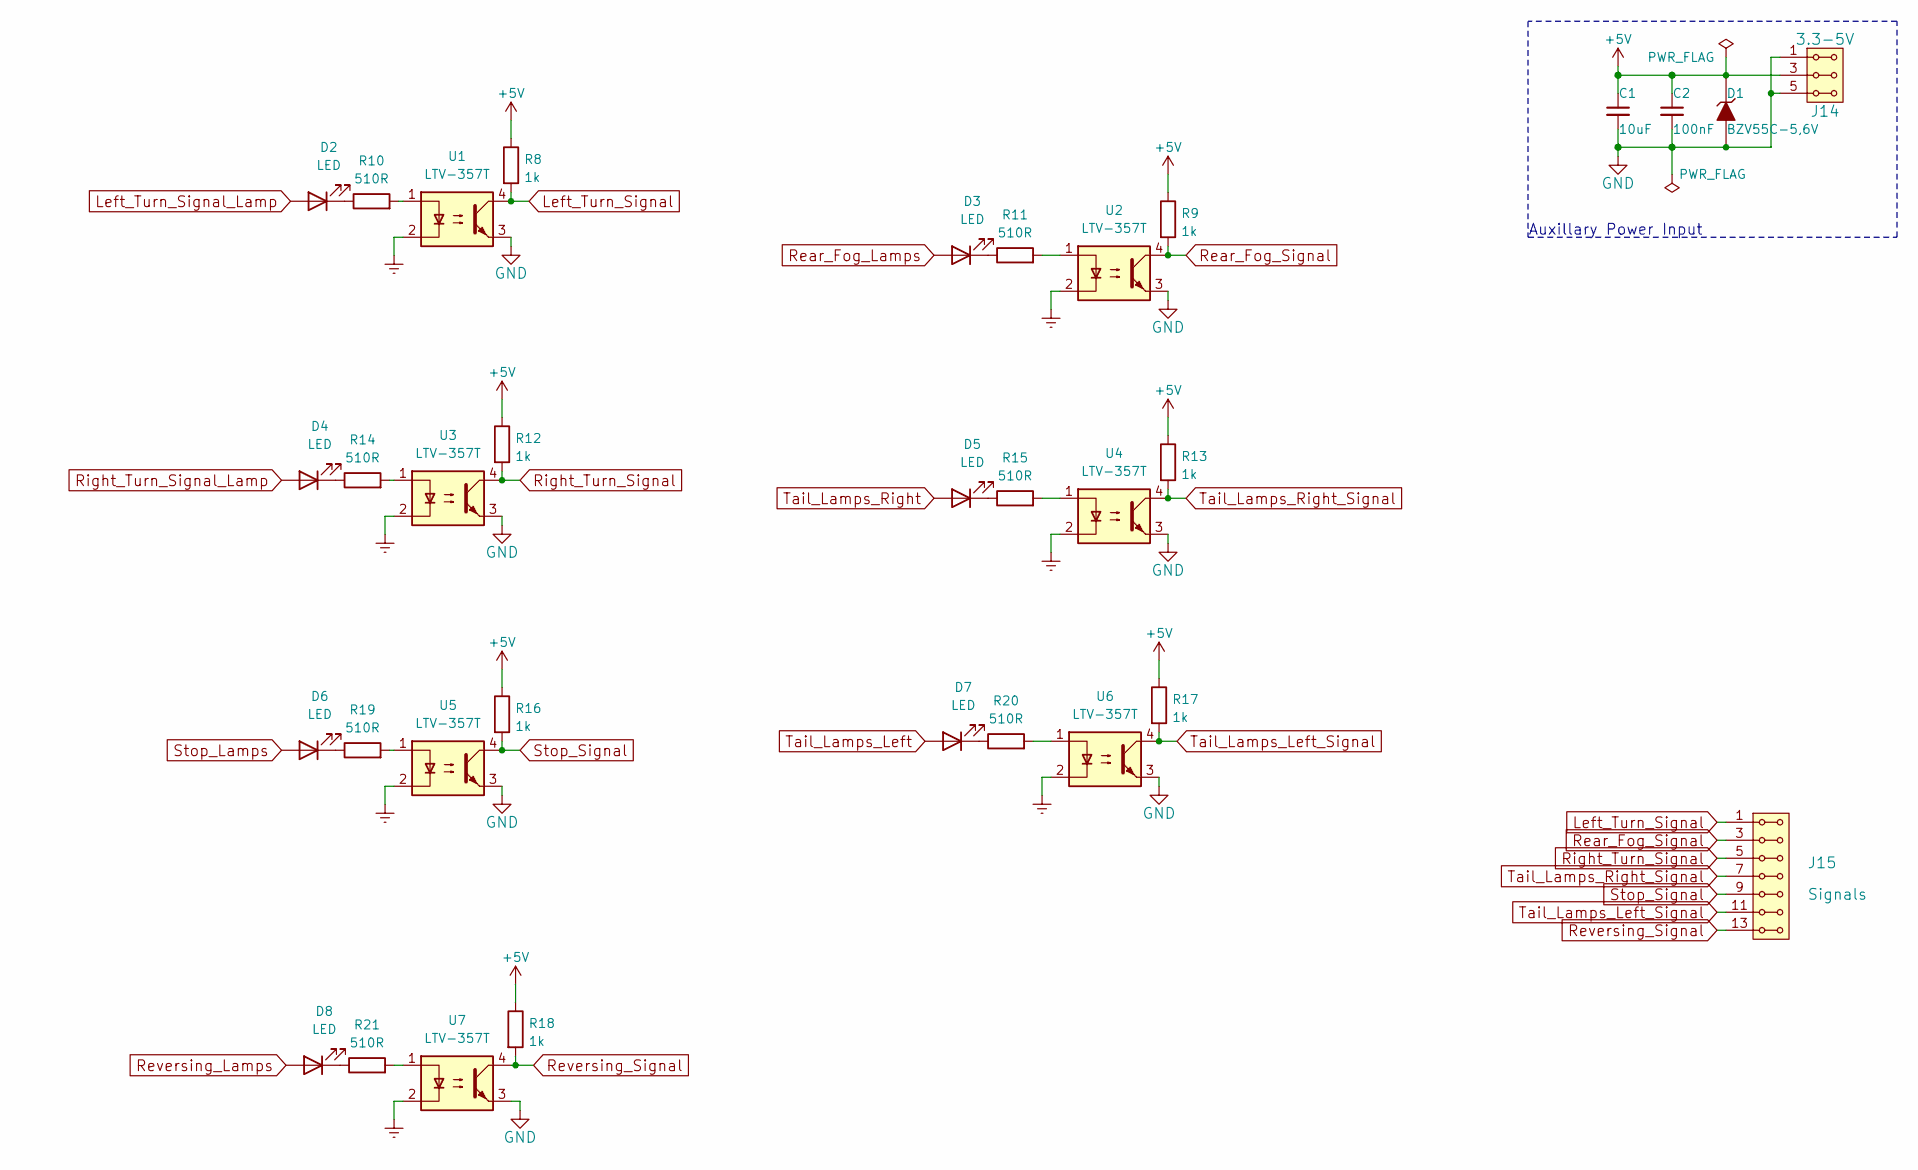
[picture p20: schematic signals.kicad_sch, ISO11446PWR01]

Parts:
C1: 10uF; SMD-0805
C2: 100nF; C_0805_2012Metric
D1: BZV55C-5,6V; D_SMA
D2, D3, D4, D5, D6, D7, D8: LED; LED_1206
J14: 3.3-5V; Straight_2x03
J15: Signals; Straight_2x07
R8, R9, R12, R13, R16, R17, R18: 1k; SMD-0805
R10, R11, R14, R15, R19, R20, R21: 510R; SMD-0805
U1, U2, U3, U4, U5, U6, U7: LTV-357T; SO-4_4.4x3.6mm_P2.54mm

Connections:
+5V: C1.1, C2.1, D1.1 (K), J14.3, J14.4, R8.1, R9.1, R12.1, R13.1, R16.1, R17.1, R18.1
Earth: U1.2, U2.2, U3.2, U4.2, U5.2, U6.2, U7.2; also elsewhere on the board
GND: C1.2, C2.2, D1.2 (A), J14.1, J14.2, J14.5, J14.6, U1.3, U2.3, U3.3, U4.3, U5.3, U6.3, U7.3
Left_Turn_Signal: J15.1, J15.2, R8.2, U1.4
Left_Turn_Signal_Lamp: D2.2 (A); also elsewhere on the board
unnamed: D2.1 (K), R10.1
unnamed: D3.1 (K), R11.1
unnamed: D4.1 (K), R14.1
unnamed: D5.1 (K), R15.1
unnamed: D6.1 (K), R19.1
unnamed: D7.1 (K), R20.1
unnamed: D8.1 (K), R21.1
unnamed: R10.2, U1.1
unnamed: R11.2, U2.1
unnamed: R14.2, U3.1
unnamed: R15.2, U4.1
unnamed: R19.2, U5.1
unnamed: R20.2, U6.1
unnamed: R21.2, U7.1
Rear_Fog_Lamps: D3.2 (A); also elsewhere on the board
Rear_Fog_Signal: J15.3, J15.4, R9.2, U2.4
Reversing_Lamps: D8.2 (A); also elsewhere on the board
Reversing_Signal: J15.13, J15.14, R18.2, U7.4
Right_Turn_Signal: J15.5, J15.6, R12.2, U3.4
Right_Turn_Signal_Lamp: D4.2 (A); also elsewhere on the board
Stop_Lamps: D6.2 (A); also elsewhere on the board
Stop_Signal: J15.9, J15.10, R16.2, U5.4
Tail_Lamps_Left: D7.2 (A); also elsewhere on the board
Tail_Lamps_Left_Signal: J15.11, J15.12, R17.2, U6.4
Tail_Lamps_Right: D5.2 (A); also elsewhere on the board
Tail_Lamps_Right_Signal: J15.7, J15.8, R13.2, U4.4

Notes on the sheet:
Auxillary Power Input

Board: 2 copper layers, 70 parts (37 on the bottom side), 41 nets, no tracks yet.

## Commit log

2023-02-09 create kicad project
    [ISO11446PWR01.kicad_pcb, ISO11446PWR01.kicad_sch]
2023-02-09 testing schema
    [ISO11446PWR01.kicad_pcb, ISO11446PWR01.kicad_sch]
2023-02-10 Update actions products
    [ISO11446PWR01-B_Adhesive.dxf, ISO11446PWR01-B_Courtyard.dxf, ISO11446PWR01-B_Cu.dxf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]
2023-02-16 An initial test implementation. Both Schema and PCB needs check.
    [ISO11446PWR01.kicad_pcb, ISO11446PWR01.kicad_sch]
2023-02-16 slove some warnings.
    [ISO11446PWR01.kicad_pcb]
2023-02-16 Improve layout and connector orientation.
    [ISO11446PWR01.kicad_pcb]
2023-02-16 drobne upravy schematu
    [ISO11446PWR01.kicad_sch]
2023-02-20 Significant schematic and layout improvement. Fixed fuse footprint Fixed schematics * Spliting to multiple sheets * Texts translated from czech to english
    [ISO11446.kicad_sch, ISO11446PWR01.kicad_pcb, ISO11446PWR01.kicad_sch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]
2026-02-14 Update to KiCADv9.
    [ISO11446.kicad_sch, ISO11446PWR01.kicad_pcb, ISO11446PWR01.kicad_sch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]
